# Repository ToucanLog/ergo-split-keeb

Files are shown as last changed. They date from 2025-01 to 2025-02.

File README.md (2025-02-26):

# ergo-split-keeb
rp2040 based split keyboard with trrs and usb-c (2.0). Using an ergodox-esque layout, but I wanted even more keys...






NOTE: The firmware is for use with QMK (https://github.com/qmk/qmk_firmware), however this keyboard does not have an official commit yet. Thus, simply copy this keyboard's firmware into a new sub-folder in the "keyboards" folder and flash from there. See the QMK CLI docs for flashing the keyboard for extra help. Please note that this firmware is exceptionally early stage, and while completely functional, is relatively bare-bones. 

`qmk flash -kb "/ENTER PATH HERE" -km default -bl uf2-split-left`

`qmk flash -kb "/ENTER PATH HERE" -km default -bl uf2-split-right`

See Schematic for 1 PCB (Left)

JasonSplitErgoKeyboard_Left-1



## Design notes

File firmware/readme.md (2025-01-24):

# jason_split_keeb

jason_split_keeb

*A short description of the keyboard/project*

* Keyboard Maintainer: [NA](https://github.com/NA)
* Hardware Supported: *The PCBs, controllers supported*
* Hardware Availability: *Links to where you can find this hardware*

Make example for this keyboard (after setting up your build environment):

    make jason_split_keeb:default

Flashing example for this keyboard:

    make jason_split_keeb:default:flash

See the [build environment setup](https://docs.qmk.fm/#/getting_started_build_tools) and the [make instructions](https://docs.qmk.fm/#/getting_started_make_guide) for more information. Brand new to QMK? Start with our [Complete Newbs Guide](https://docs.qmk.fm/#/newbs).

## Bootloader

Enter the bootloader in 3 ways:

* **Bootmagic reset**: Hold down the key at (0,0) in the matrix (usually the top left key or Escape) and plug in the keyboard
* **Physical reset button**: Briefly press the button on the back of the PCB - some may have pads you must short instead
* **Keycode in layout**: Press the key mapped to `QK_BOOT` if it is available

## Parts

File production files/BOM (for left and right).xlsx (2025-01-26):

Comment | Designator | Footprint | JLCPCB Part#(optional)
10uF | C1,C2 | 0603
15pF | C3,C4 | 0603
100nF | C5-7, C10-16 | 0603
1uF | C8,C9 | 0603
1N4148WS | D1-41 | SOD-323
1N5819WS | D42 | SOD-323
USB-C (GT-USB-7010ASV) | J1 | GT-USB-7010ASV
PJ-320D | J2 | 3.5mm_PJ320D_Horizontal
SKRKAEE020 | SW42,SW43 | SMD - Custom
5.1kΩ | R2,R3 | 0603
1kΩ | R5 | 0603
27.4Ω | R6,R7 | 0603
2.2kΩ | R8,R9 | 0603
NCP1117 | U1 | SOT-223-3
W25Q128JVS | U2 | SOIC-8-208mil
RP2040 | U3 | LQFN-56(7x7)
12MHz | Y1 | SMD3225-4P

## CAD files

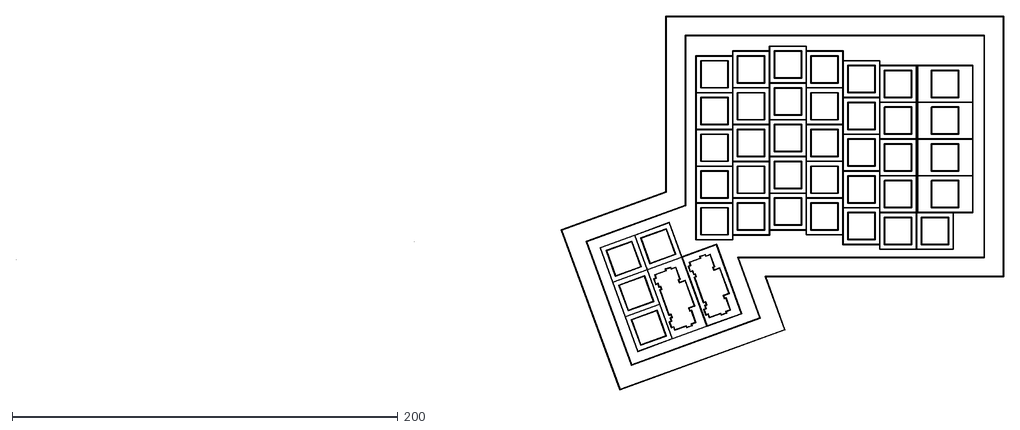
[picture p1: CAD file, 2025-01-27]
enclosure files/right plate with extra geometry.dxf
511.8 x 193.6

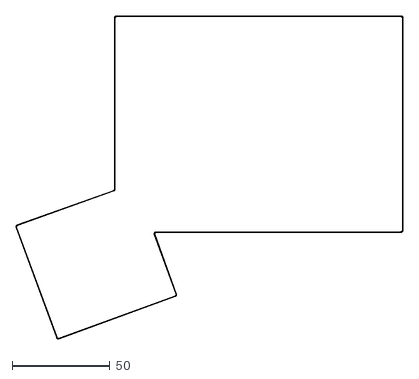
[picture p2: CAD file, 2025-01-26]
production files/RIGHT GERBER/GERBER/JasonSplitErgoKeyboard_Right-Edge_Cuts.dxf
197.9 x 165.2

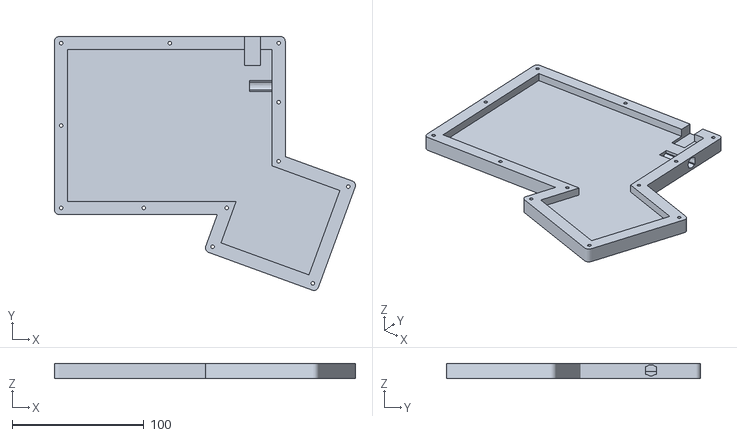
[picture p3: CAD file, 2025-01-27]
enclosure files/Left Bottom.stl
228.1 x 192.4 x 11.0

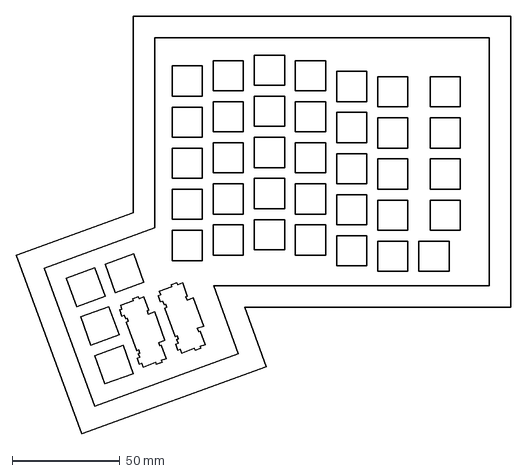
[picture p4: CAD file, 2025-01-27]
enclosure files/right plate.dxf
229.1 x 193.4 mm

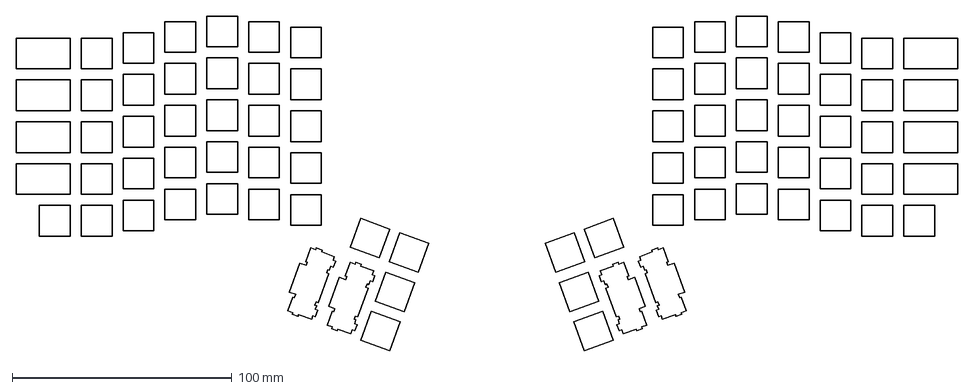
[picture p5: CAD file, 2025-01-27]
enclosure files/left and right plates.dxf
428.6 x 152.4 mm

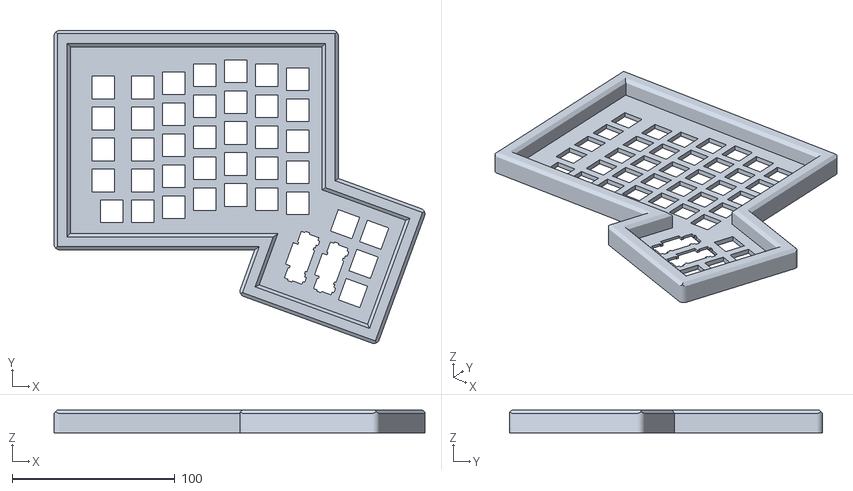
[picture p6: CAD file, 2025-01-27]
enclosure files/Left Hand Plate.stl
228.1 x 192.5 x 14.0

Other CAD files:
enclosure files/RIght Bottom.stl
enclosure files/Right Hand Plate.stl

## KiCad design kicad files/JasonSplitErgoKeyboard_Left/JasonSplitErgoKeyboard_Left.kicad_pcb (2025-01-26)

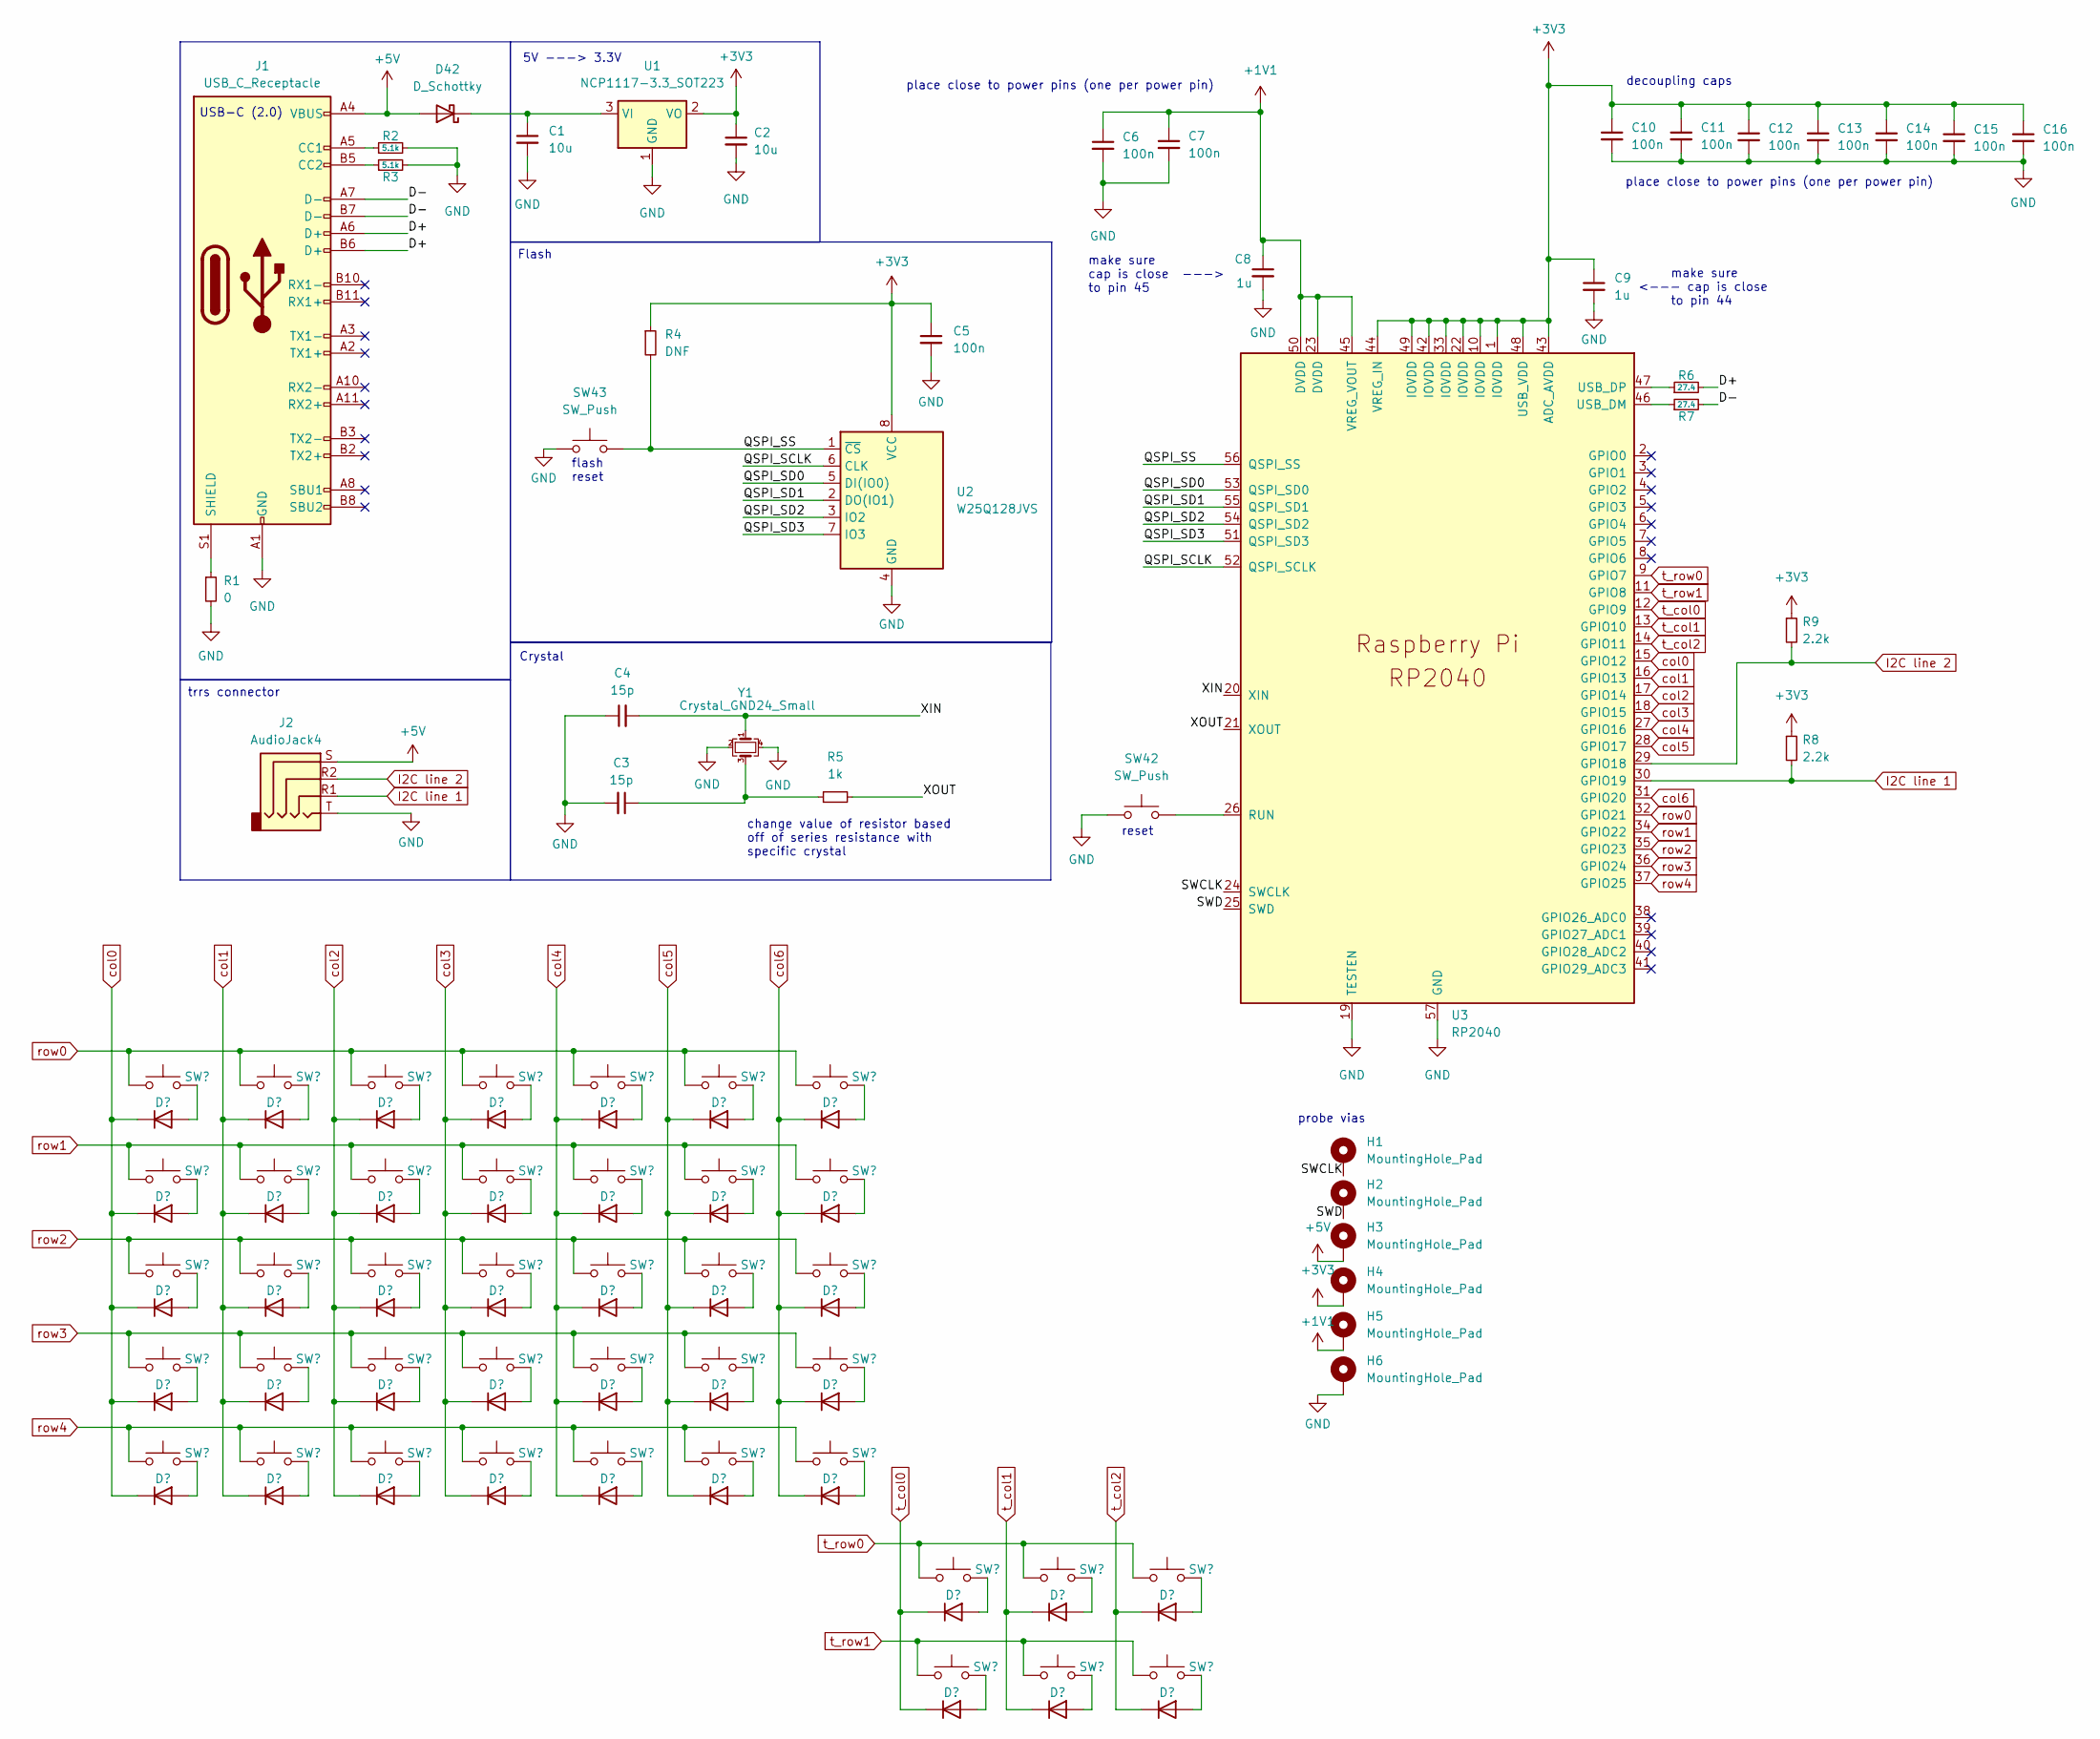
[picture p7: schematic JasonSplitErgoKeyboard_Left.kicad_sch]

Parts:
C1, C2: 10u; C_0603_1608Metric
C3, C4: 15p; C_0603_1608Metric
C5, C6, C7, C10, C11, C12, C13, C14, C15, C16: 100n; C_0603_1608Metric
C8, C9: 1u; C_0603_1608Metric
D1, D2, D3, D4, D5, D6, D7, D8, D9, D10, D11, D12, D13, D14, D15, D16, D17, D18, D19, D20, D21, D22, D23, D24, D25, D26, D27, D28, D29, D30, D31, D32, D33, D34, D35, D36, D37, D38, D39, D40, D41: D; D_SOD-323
D42: D_Schottky; D_SOD-323
H1, H2, H3, H4, H5, H6: MountingHole_Pad; MountingHole_2.2mm_M2_DIN965_Pad
J1: USB_C_Receptacle; USB_C_Receptacle_G-Switch_GT-USB-7010ASV
J2: AudioJack4; Jack_3.5mm_PJ320D_Horizontal
R1: 0; R_0603_1608Metric
R2, R3: 5.1k; R_0603_1608Metric
R4: DNF; R_0603_1608Metric
R5: 1k; R_0603_1608Metric
R6, R7: 27.4; R_0603_1608Metric
R8, R9: 2.2k; R_0603_1608Metric
SW1, SW2, SW3, SW4, SW7, SW8, SW9, SW10, SW11, SW12, SW13, SW14, SW15, SW16, SW17, SW18, SW19, SW20, SW21, SW22, SW23, SW24, SW25, SW26, SW27, SW28, SW29, SW30, SW31, SW32, SW33, SW34, SW35, SW36, SW41: SW_Push; SW_Cherry_MX_1.00u_PCB
SW5, SW6: SW_Push; SW_Cherry_MX_2.00u_PCB
SW37, SW38, SW39, SW40: SW_Push; SW_Cherry_MX_1.50u_PCB
SW42, SW43: SW_Push; 3.9×2.9mm Compact Type
U1: NCP1117-3.3_SOT223; SOT-223-3_TabPin2
U2: W25Q128JVS; SOIC-8_5.23x5.23mm_P1.27mm
U3: RP2040; QFN-56-1EP_7x7mm_P0.4mm_EP4x4mm
Y1: Crystal_GND24_Small; Crystal_SMD_3225-4Pin_3.2x2.5mm

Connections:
+1V1: C6.1, C7.1, C8.1, H5.1, U3.23 (DVDD), U3.45 (VREG_VOUT), U3.50 (DVDD)
+3V3: C2.1, C5.1, C9.1, C10.1, C11.1, C12.1, C13.1, C14.1, C15.1, C16.1, H4.1, R4.1, R8.1, R9.1, U1.2 (VO), U2.8 (VCC), U3.1 (IOVDD), U3.10 (IOVDD), U3.22 (IOVDD), U3.33 (IOVDD), U3.42 (IOVDD), U3.43 (ADC_AVDD), U3.44 (VREG_IN), U3.48 (USB_VDD), U3.49 (IOVDD)
+5V: D42.2 (A), H3.1, J1.A4 (VBUS), J1.A9 (VBUS), J1.B4 (VBUS), J1.B9 (VBUS), J2.S
/D+: J1.A6 (D+), J1.B6 (D+), R6.2
/D-: J1.A7 (D-), J1.B7 (D-), R7.2
/QSPI_SCLK: U2.6 (CLK), U3.52 (QSPI_SCLK)
/QSPI_SD0: U2.5 (DI(IO0)), U3.53 (QSPI_SD0)
/QSPI_SD1: U2.2 (DO(IO1)), U3.55 (QSPI_SD1)
/QSPI_SD2: U2.3 (IO2), U3.54 (QSPI_SD2)
/QSPI_SD3: U2.7 (IO3), U3.51 (QSPI_SD3)
/QSPI_SS: R4.2, SW43.2, U2.1 (~CS), U3.56 (QSPI_SS)
/SWCLK: H1.1, U3.24 (SWCLK)
/SWD: H2.1, U3.25 (SWD)
/XIN: C4.2, U3.20 (XIN), Y1.1
/XOUT: R5.2, U3.21 (XOUT)
GND: C1.2, C2.2, C3.2, C4.1, C5.2, C6.2, C7.2, C8.2, C9.2, C10.2, C11.2, C12.2, C13.2, C14.2, C15.2, C16.2, H6.1, J1.A1 (GND), J1.A12 (GND), J1.B1 (GND), J1.B12 (GND), J2.T, R1.2, R2.2, R3.2, SW42.1, SW43.1, U1.1 (GND), U2.4 (GND), U3.19 (TESTEN), U3.57 (GND), Y1.2, Y1.4
I2C line 1: J2.R1, R8.2, U3.30 (GPIO19)
I2C line 2: J2.R2, R9.2, U3.29 (GPIO18)
unnamed: C3.1, R5.1, Y1.3
unnamed: D1.2 (A), SW1.2
unnamed: D2.2 (A), SW2.2
unnamed: D3.2 (A), SW3.2
unnamed: D4.2 (A), SW4.2
unnamed: D5.2 (A), SW5.2
unnamed: D6.2 (A), SW6.2
unnamed: D7.2 (A), SW7.2
unnamed: D8.2 (A), SW8.2
unnamed: D9.2 (A), SW9.2
unnamed: D10.2 (A), SW10.2
unnamed: D11.2 (A), SW11.2
unnamed: D12.2 (A), SW12.2
unnamed: D13.2 (A), SW13.2
unnamed: D14.2 (A), SW14.2
unnamed: D15.2 (A), SW15.2
unnamed: D16.2 (A), SW16.2
unnamed: D17.2 (A), SW17.2
unnamed: D18.2 (A), SW18.2
unnamed: D19.2 (A), SW19.2
unnamed: D20.2 (A), SW20.2
unnamed: D21.2 (A), SW21.2
unnamed: D22.2 (A), SW22.2
unnamed: D23.2 (A), SW23.2
unnamed: D24.2 (A), SW24.2
unnamed: D25.2 (A), SW25.2
unnamed: D26.2 (A), SW26.2
unnamed: D27.2 (A), SW27.2
unnamed: D28.2 (A), SW28.2
unnamed: D29.2 (A), SW29.2
unnamed: D30.2 (A), SW30.2
unnamed: D31.2 (A), SW31.2
unnamed: D32.2 (A), SW32.2
unnamed: D33.2 (A), SW33.2
unnamed: D34.2 (A), SW34.2
unnamed: D35.2 (A), SW35.2
unnamed: D36.2 (A), SW36.2
unnamed: D37.2 (A), SW37.2
unnamed: D38.2 (A), SW38.2
unnamed: D39.2 (A), SW39.2
unnamed: D40.2 (A), SW40.2
unnamed: D41.2 (A), SW41.2
unnamed: C1.1, D42.1 (K), U1.3 (VI)
unnamed: J1.A5 (CC1), R2.1
unnamed: J1.B5 (CC2), R3.1
unnamed: J1.S1 (SHIELD), R1.1
unnamed: SW42.2, U3.26 (RUN)
unnamed: R7.1, U3.46 (USB_DM)
unnamed: R6.1, U3.47 (USB_DP)
col0: D7.1 (K), D8.1 (K), D9.1 (K), D10.1 (K), D11.1 (K), U3.15 (GPIO12)
col1: D12.1 (K), D13.1 (K), D14.1 (K), D15.1 (K), D16.1 (K), U3.16 (GPIO13)
col2: D17.1 (K), D18.1 (K), D19.1 (K), D20.1 (K), D21.1 (K), U3.17 (GPIO14)
col3: D22.1 (K), D23.1 (K), D24.1 (K), D25.1 (K), D26.1 (K), U3.18 (GPIO15)
col4: D27.1 (K), D28.1 (K), D29.1 (K), D30.1 (K), D31.1 (K), U3.27 (GPIO16)
col5: D32.1 (K), D33.1 (K), D34.1 (K), D35.1 (K), D36.1 (K), U3.28 (GPIO17)
col6: D37.1 (K), D38.1 (K), D39.1 (K), D40.1 (K), D41.1 (K), U3.31 (GPIO20)
row0: SW7.1, SW12.1, SW17.1, SW22.1, SW27.1, SW32.1, SW37.1, U3.32 (GPIO21)
row1: SW8.1, SW13.1, SW18.1, SW23.1, SW28.1, SW33.1, SW38.1, U3.34 (GPIO22)
row2: SW9.1, SW14.1, SW19.1, SW24.1, SW29.1, SW34.1, SW39.1, U3.35 (GPIO23)
row3: SW10.1, SW15.1, SW20.1, SW25.1, SW30.1, SW35.1, SW40.1, U3.36 (GPIO24)
row4: SW11.1, SW16.1, SW21.1, SW26.1, SW31.1, SW36.1, SW41.1, U3.37 (GPIO25)
t_col0: D1.1 (K), D6.1 (K), U3.12 (GPIO9)
t_col1: D2.1 (K), D5.1 (K), U3.13 (GPIO10)
t_col2: D3.1 (K), D4.1 (K), U3.14 (GPIO11)
t_row0: SW1.1, SW2.1, SW3.1, U3.9 (GPIO7)
t_row1: SW4.1, SW5.1, SW6.1, U3.11 (GPIO8)

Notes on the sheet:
trrs connector
Flash
reset
make sure <--- cap is close to pin 44
flash reset
probe vias
place close to power pins (one per power pin)
5V ---> 3.3V
change value of resistor based off of series resistance with specific crystal
make sure cap is close ---> to pin 45
Crystal
decoupling caps
USB-C (2.0)

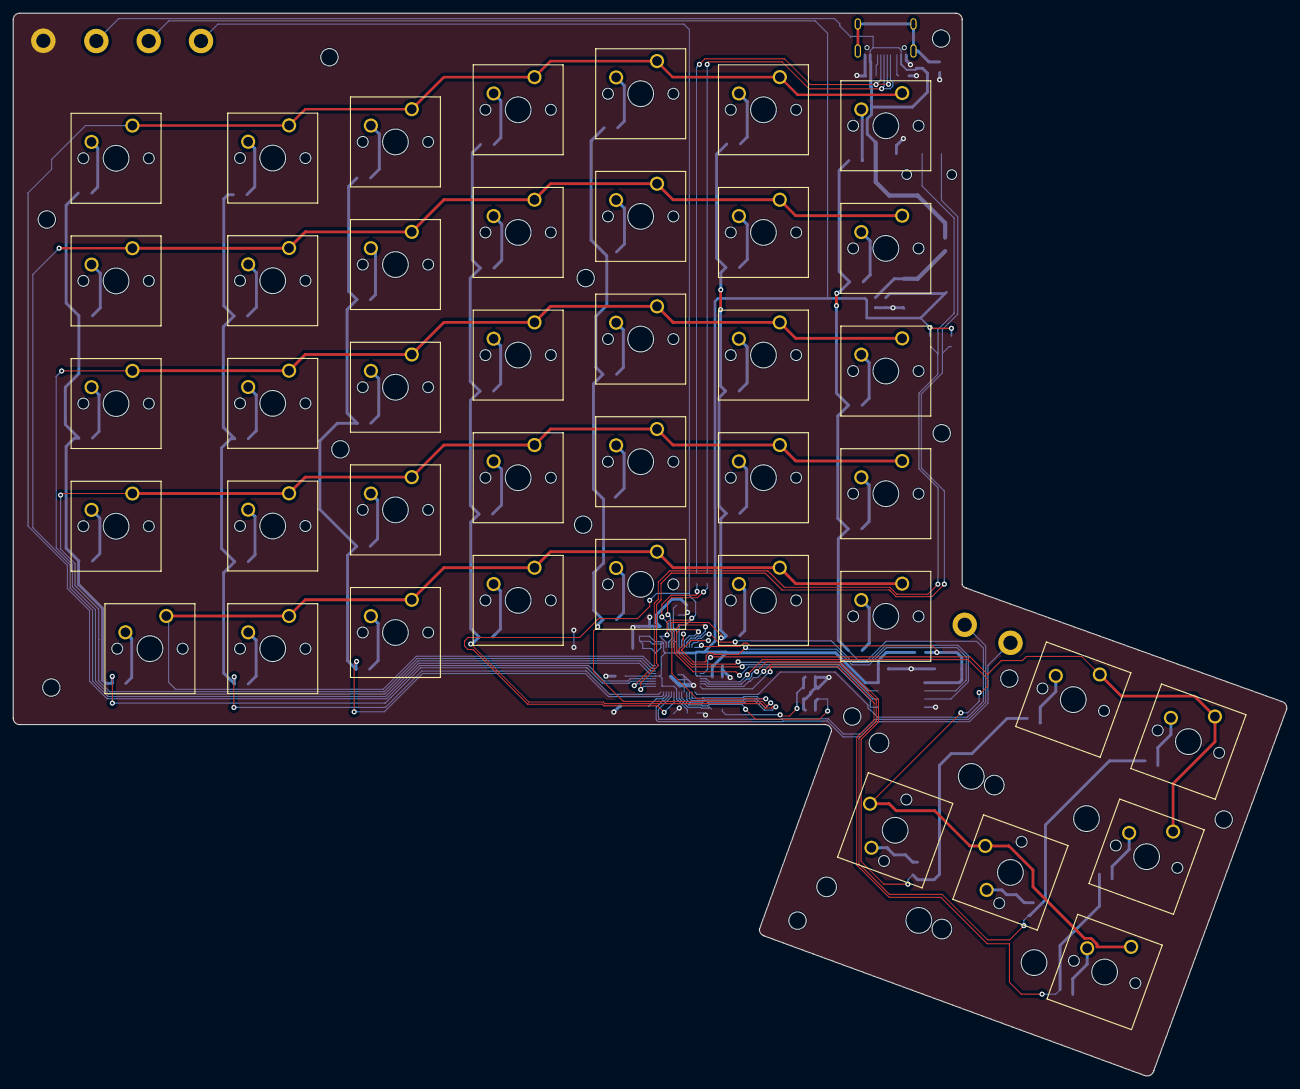
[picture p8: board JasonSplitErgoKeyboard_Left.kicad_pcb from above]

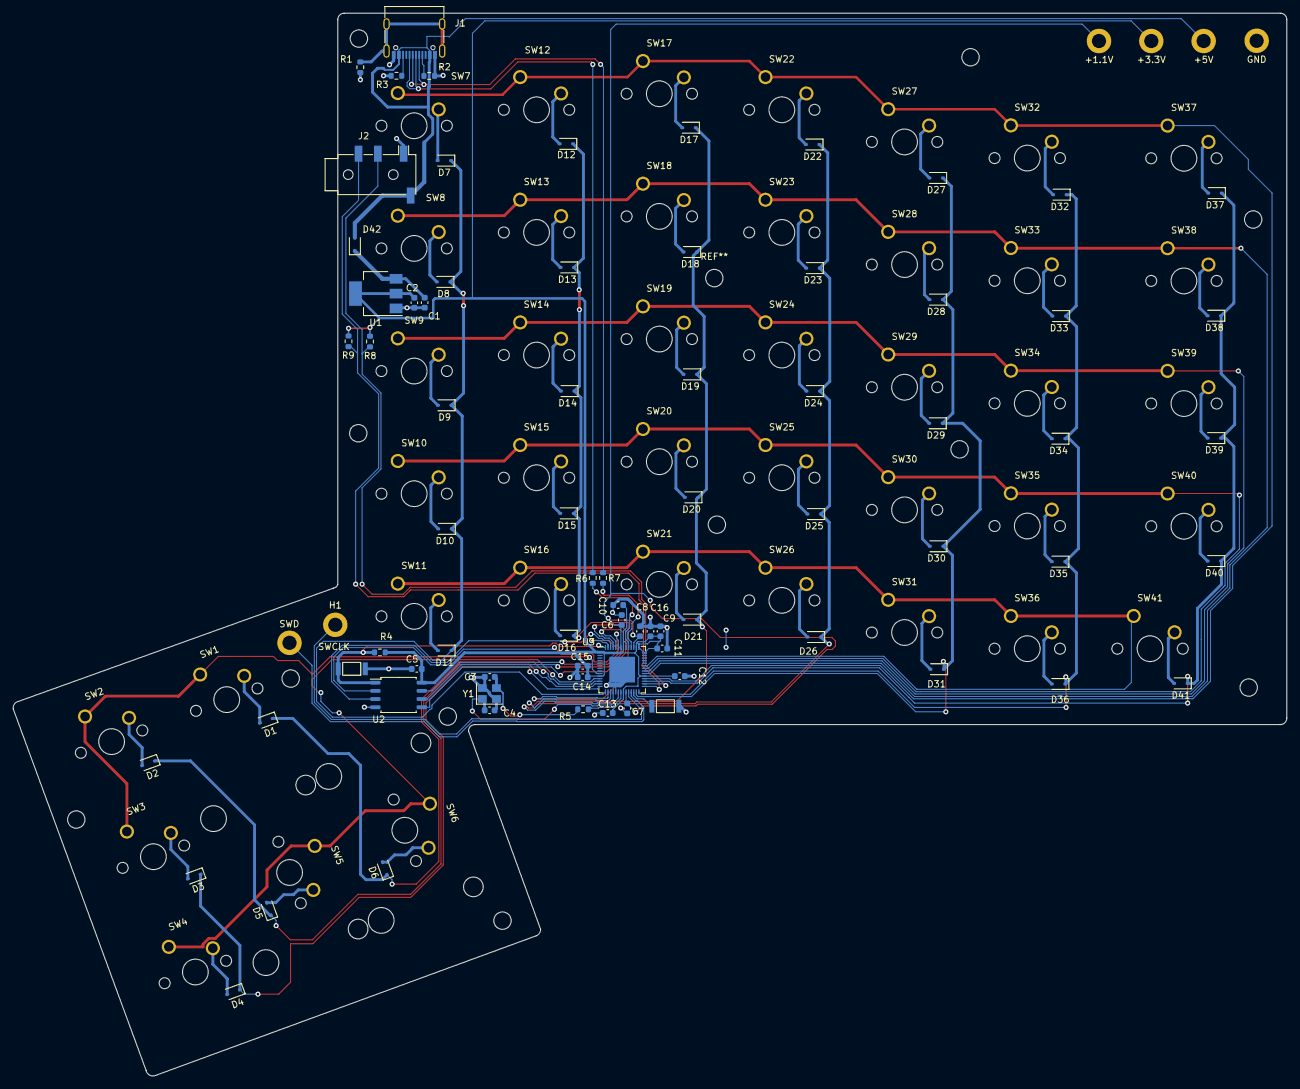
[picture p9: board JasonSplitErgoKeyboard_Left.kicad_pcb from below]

Board: 2 copper layers, 197.8 x 165.1 mm, 122 parts (81 on the bottom side), 84 nets.

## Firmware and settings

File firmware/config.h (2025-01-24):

#pragma once
 
#define SPLIT_USB_DETECT

#define EE_HANDS /* see https://docs.qmk.fm/features/split_keyboard#serial-wiring */
#define SPLIT_USB_DETECT
#define USE_SERIAL

// #define SOFT_SERIAL_PIN GP13
// #define SERIAL_PIO_USE_PIO1

#define SERIAL_USART_FULL_DUPLEX
#define SERIAL_USART_TX_PIN GP18
#define SERIAL_USART_RX_PIN GP19
#define SERIAL_USART_PIN_SWAP

/* key matrix size */
#define MATRIX_ROWS 14
#define MATRIX_COLS 10

#define MATRIX_ROW_PINS { GP21, GP22, GP23, GP24, GP25, GP7, GP8 }
#define MATRIX_COL_PINS { GP12, GP13, GP14, GP15, GP16, GP17, GP20, GP9, GP10, GP11 }
#define MATRIX_ROW_PINS_RIGHT { GP21, GP22, GP23, GP24, GP25, GP14, GP15 }
#define MATRIX_COL_PINS_RIGHT { GP13, GP12, GP11, GP10, GP9, GP8, GP7, GP16, GP17, GP20 }

#define DIODE_DIRECTION ROW2COL

#define SERIAL_DEBUG

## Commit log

2025-01-26 adding pcb files, including both kicad and prodcution gerber
    [BOM (for left and right).xlsx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]
2025-01-27 adding enclosure files
    [Left Bottom.stl, Left Hand Plate.stl, RIght Bottom.stl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]
